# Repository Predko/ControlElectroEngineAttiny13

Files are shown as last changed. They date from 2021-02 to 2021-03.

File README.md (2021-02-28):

# ControlElectroEngineAttiny13

Прошивка для Attiny13.
Предназначена для управления запуском трёхфазного ассинхронного двигателя, подключённого к двухфазной сети.
Запуск осуществляется путём подключения пускового конденсатора с помощью реле.
Микроконтроллер замеряет ток через фазу двигателя с помощью датчика тока(ACS712, 30А) 
и при превышении значения тока в 1.5 раза, подключает пусковой конденсатор.
Если через 3 секунды ток не уменьшается, двигатель отключается на 10 секунд, при этом подаётся звуковой сигнал.
Затем цикл запуска повторяется.
Если за 3 цикла запуска, двигатель не запустился, питание отключается.

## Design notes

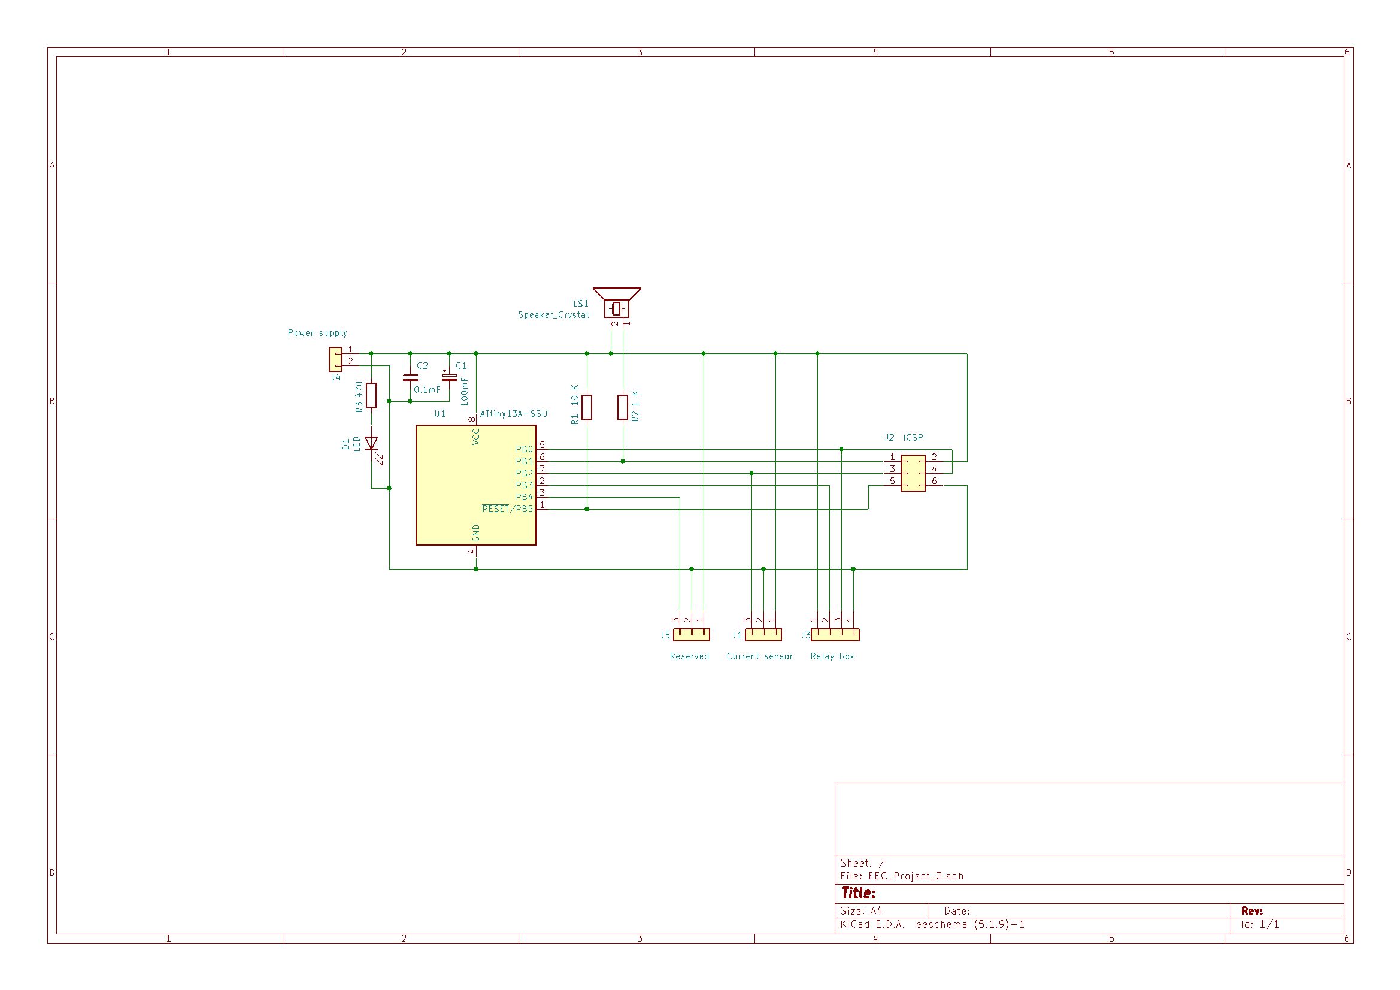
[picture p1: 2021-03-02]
Schema_V2.jpg

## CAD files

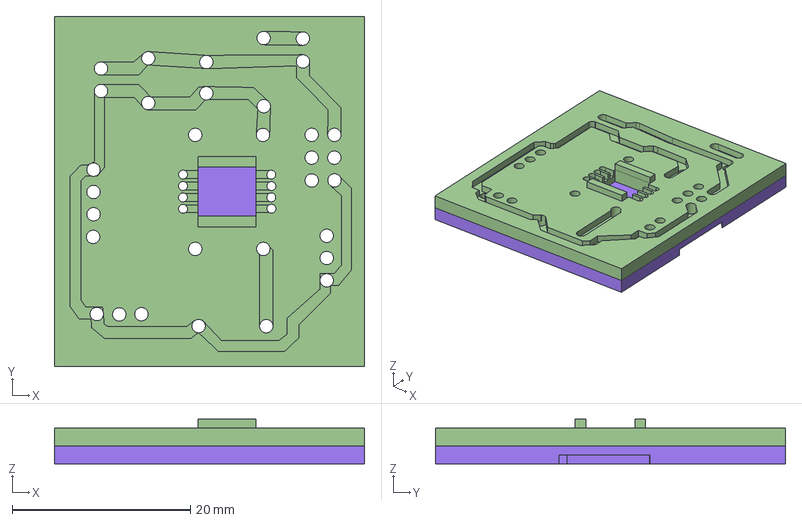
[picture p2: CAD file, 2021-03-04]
PCB/FreeCad/ControlElectroEngine.FCStd
34.7 x 39.2 x 5.00 mm
Slice.0
Slice.1

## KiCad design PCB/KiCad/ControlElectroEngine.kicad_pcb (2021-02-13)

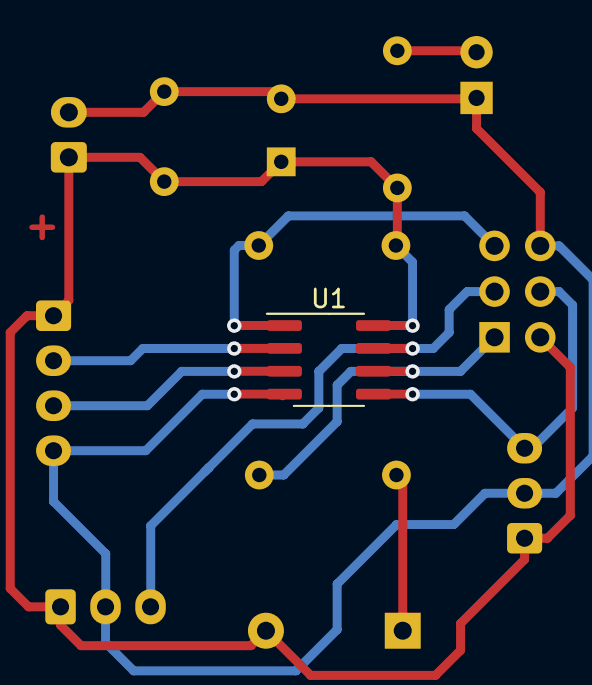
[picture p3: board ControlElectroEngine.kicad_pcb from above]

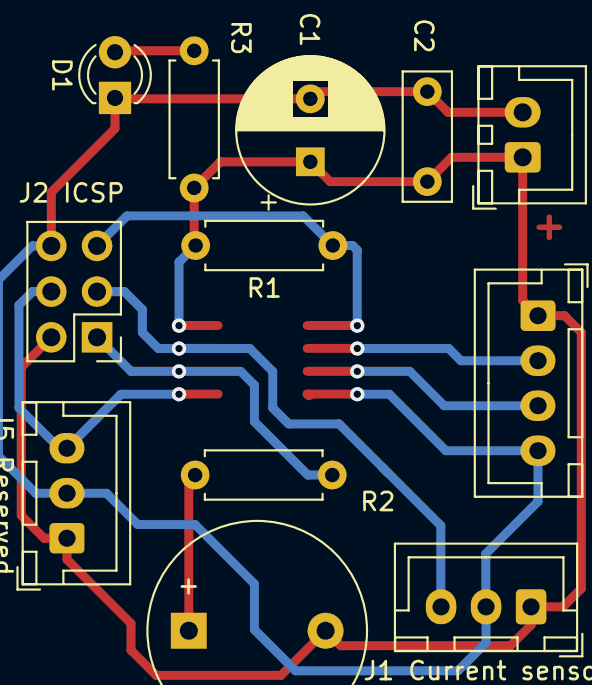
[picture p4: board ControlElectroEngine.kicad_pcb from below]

Board: 2 copper layers, 13 parts (12 on the bottom side), 10 nets.

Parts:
C1: 100mF; CP_Radial_D8.0mm_P3.50mm
C2: 0,1mF; C_Disc_D7.0mm_W2.5mm_P5.00mm
D1: LED; LED_D3.0mm_Clear
J1 Current sensor: Current sensor; JST_XH_B3B-XH-A_1x03_P2.50mm_Vertical
J2 ICSP: ICSP; PinHeader_2x03_P2.54mm_Vertical
J3 Relay: Relay box; JST_XH_B4B-XH-A_1x04_P2.50mm_Vertical
J4 5v: Power supply; JST_XH_B2B-XH-A_1x02_P2.50mm_Vertical
J5 Reserved: Reserved; JST_XH_B3B-XH-A_1x03_P2.50mm_Vertical
LS1: Speaker_Crystal; Buzzer_12x9.5RM7.6
R1: 10 K; R_Axial_DIN0207_L6.3mm_D2.5mm_P7.62mm_Horizontal
R2: 1 K; R_Axial_DIN0207_L6.3mm_D2.5mm_P7.62mm_Horizontal
R3: 470; R_Axial_DIN0207_L6.3mm_D2.5mm_P7.62mm_Horizontal
U1: ATtiny13A-SSU; SOIC-8_3.9x4.9mm_P1.27mm

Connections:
unnamed: C1.1, C2.1, J1 Current sensor.1, J2 ICSP.2, J3 Relay.1, J4 5v.1, J5 Reserved.1, LS1.2, R1.2, R3.2, U1.8
unnamed: C1.2, C2.2, D1.1, J1 Current sensor.2, J2 ICSP.6, J3 Relay.4, J4 5v.2, J5 Reserved.2, U1.4
unnamed: D1.2, R3.1
unnamed: J1 Current sensor.3, J2 ICSP.3, U1.7
unnamed: J2 ICSP.1, R2.2, U1.6
unnamed: J2 ICSP.4, J5 Reserved.3, U1.5
unnamed: J2 ICSP.5, R1.1, U1.1
unnamed: J3 Relay.2, U1.2
unnamed: J3 Relay.3, U1.3
unnamed: LS1.1, R2.1

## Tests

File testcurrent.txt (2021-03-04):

:1
F2		242	
F3		243
3601	310
8A FE F3 F3 F3 F3 F3 F3 F3 F3 F3 B1 B2 00 F2 0D F2 F2 AD 8B 8C 84 8E

17
EB01

:2
F1 F2
1801
F2 F3 F2 F2 F2 F2 F3 F2 F2 F2 F2 F2 F1 F2 F1 F2 F2 F2 F1 F2 F1 - с конденсатором 21 изм
AF AE B1 AF B0 B2 AF B1 B0 AF B1 B0 AF B0 B1 AF B2	- без 17 изм
0000
26 - число измерений
5A02

F3 F3 
1701

F3 F3 F3 F3 F2 F3 - 243 = 24 А
F3 F3 F3 F3 F3 F3 F3 F3 F3 F3 F3 F3 F3 F3

00
14
00 Отключение конденсатора.
					B0 = 176 = 10 А
F2 AE AD B0 B1 25 AE B1 AE B1 B0 AF B1 B1 B0 B1 B1 B0 B0 B1 B1

0000

28

5702

:3
Старт.
F1 F1 	- 241 = 23.65 А
1901 

F1 F1 F1 F1 F1 F0 
Включение конденсатора.
{F1 E6} ED EF F0 E8 EF EF F1 EF F1 EF EA F0 	- (21.35 - 23.65 А)
{время запуска ~ 0.5 сек)
00 14 00
Отключение конденсатора.
F1 B5 B3 B4 B3 68 B4 B4 B3 B5 B5 B5 B4 B5 B3 B5 B4 B5 B5 - B4 = 10.0 А

0000

26

6002

5702

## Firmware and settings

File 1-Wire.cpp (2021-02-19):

    // https://forum.sources.ru/index.php?showtopic=381077
    #include <inttypes.h>
    #include <string.h>
    #include <avr/io.h>
    #include <util/delay.h>
    #include <avr/interrupt.h>
     
    // --- Configuration for OneWire
    #define ONEWIRE_PORTReg     PORTB
    #define ONEWIRE_DDRReg      DDRB
    #define ONEWIRE_PINReg      PINB
    #define ONEWIRE_PIN         PB0
     
    // --- Configure for PWM (fan)
    #define PWM_PORTReg         PORTB
    #define PWM_DDRReg          DDRB
    #define PWM_PIN             PB1
     
    // - Minimal temperature to activate fan
    #define FAN_MIN_TEMPERATURE 40
     
    // - Temperature for maximum fan power
    #define FAN_MAX_TEMPERATURE 70
     
    // - Power, used to start fan. Must be enough to start!
    #define FAN_START_PWM_VALUE 200
    #define FAN_START_TIME      2000
     
    // - Minimal fan power
    #define FAN_MIN_POWER       60
     
    // - Maximal fan power
    #define FAN_MAX_POWER       255
     
    // - Configure for alarm
    #define ALARM_PORTReg               PORTB
    #define ALARM_DDRReg                DDRB
    #define ALARM_PIN                   PB2
     
    #define ALARM_ON_MAX_ERRORS         16
    #define ALARM_ON_MAX_TEMPERATURE    80
     
     
     
    // - Set OneWire pin in Output mode
    #define OneWire_setPinAsOutput  ONEWIRE_DDRReg |= (1<<ONEWIRE_PIN)
     
    // - Set OneWire pin in Input mode
    #define OneWire_setPinAsInput   ONEWIRE_DDRReg &= ~(1<<ONEWIRE_PIN)
     
    // - Set LOW level on OneWire pin
    #define OneWire_writePinLOW     ONEWIRE_PORTReg &=  ~(1<<ONEWIRE_PIN)
     
    // - Set HIGH level on OneWire pin
    #define OneWire_writePinHIGH    ONEWIRE_PORTReg |= (1<<ONEWIRE_PIN)
     
    // - Read level from OneWire pin
    #define OneWire_readPin         ( ( ONEWIRE_PINReg & (1<<ONEWIRE_PIN) ) ? 1 : 0 )
     
     
    // - Turn on alarm
    #define Alarm_On    ALARM_PORTReg |= (1<<ALARM_PIN);
     
    // - Turn off alarm
    #define Alarm_Off   ALARM_PORTReg &= ~(1<<ALARM_PIN);
     
    // - PWM Value ( 0 - off, 255 - max )
    uint8_t PWMValue    = 0;
     
    // - Oveflow counter for PWM
    uint8_t PWMCounter  = 0;
    uint8_t PWM         = 0;
     
     
    //! Calculate CRC-8
    uint8_t crc8(const uint8_t * addr, uint8_t len){
        uint8_t crc = 0;
        while (len--) {
            uint8_t inbyte = *addr++;
            for (uint8_t i = 8; i; i--) {
                uint8_t mix = (crc ^ inbyte) & 0x01;
                crc >>= 1;
                if (mix) crc ^= 0x8C;
                inbyte >>= 1;
            }
        }
        return crc;
    }
     
    //! Reset function
    uint8_t OneWire_reset(){
        
        // - Wait for line
        uint8_t Retries = 125;
        OneWire_setPinAsInput;
        do{
            if( --Retries == 0 ) return 0;
            _delay_us( 2 );
        }while( !OneWire_readPin );
        
        // - Drop line
        OneWire_writePinLOW;
        OneWire_setPinAsOutput;
        _delay_us( 480 );
        
        // - Listen for reply pulse
        OneWire_setPinAsInput;
        _delay_us( 70 );
        
        // - Read line state
        uint8_t State = !OneWire_readPin;
        _delay_us( 410 );
        return State;
    }
     
    //! Write single bit
    void OneWire_writeBit( uint8_t Bit ){
        if( Bit & 1 ){
            // - Drop line
            OneWire_writePinLOW;
            OneWire_setPinAsOutput;
            // - Write Bit-1
            _delay_us( 10 );
            OneWire_writePinHIGH;
            _delay_us( 55 );
        }else{
            // - Drop line
            OneWire_writePinLOW;
            OneWire_setPinAsOutput;
            // - Write Bit-0
            _delay_us( 65 );
            OneWire_writePinHIGH;
            _delay_us( 5 );
        }
    }
     
    //! Read single bit
    uint8_t OneWire_readBit(){
        // - Drop line
        OneWire_setPinAsOutput;
        OneWire_writePinLOW;
        _delay_us( 3 );
        
        // - Wait for data
        OneWire_setPinAsInput;
        _delay_us( 10 );
        
        // - Read bit into byte
        uint8_t Bit = OneWire_readPin;
        _delay_us( 53 );
        return Bit;
    }
     
    //! Write byte
    inline void OneWire_writeByte( const uint8_t Byte, uint8_t Power = 0 ){
        
        // - Write each bit
        for( uint8_t BitMask = 0x01; BitMask; BitMask <<= 1 ) OneWire_writeBit( (BitMask & Byte) ? 1 : 0 );
        
        // - Disable power
        if( !Power ){
            OneWire_setPinAsInput;
            OneWire_writePinLOW;
        }
    }
    //! Read byte
    inline uint8_t OneWire_readByte(){
        uint8_t Byte = 0;
        
        // - Read all bits
        for( uint8_t BitMask = 0x01; BitMask; BitMask <<= 1 ){
            // - Read & store bit into byte
            if( OneWire_readBit() ) Byte |= BitMask;
        }
        return Byte;
    }
     
     
    //! Read buffer
    inline void OneWire_read( uint8_t * Buffer, uint8_t Size ){
        for( uint8_t i = 0; i < Size; i++ ) Buffer[ i ] = OneWire_readByte();
    }
     
    //! Write buffer
    inline void OneWire_write(const uint8_t * Buffer, uint8_t Size, uint8_t Power = 0 ){
        for( uint8_t i = 0; i < Size; i++ )  OneWire_writeByte(  Buffer[ i ] );
        if( !Power ){
            // - Disable power
            OneWire_setPinAsInput;
            OneWire_writePinLOW;
        }
    }
     
    //! Map one range to another
    uint16_t map( uint16_t x, uint16_t in_min, uint16_t in_max, uint16_t out_min, uint16_t out_max){
      return (x - in_min) * (out_max - out_min) / (in_max - in_min) + out_min;
    }
     
     
    //! Main function
    int main() {
        
        // - Configure alarm pin
        ALARM_DDRReg |= ( 1 << PB2 );
        
        // - Configure PWM pin
        PWM_DDRReg |= ( 1 << PB1 );
        
        // - Configure timer for PWM
        TIMSK0      = 0b00000010;
        TCCR0B      = 0b00000001;
        
        // - Allow interrupts
        sei();
        
        // - Buffer for ROM
        uint8_t ROM[ 9 ];
        
        // - Fan state
        uint8_t FanState    = 0;
        
        // - Error count
        uint8_t ErrorCount  = 0;
        
        // - Main loop
        while( 1 ){
            // - Check error count
            if( ErrorCount >= ALARM_ON_MAX_ERRORS ){
                // - Force start fan at 100% power
                PWMValue    = 255;
                FanState    = 1;
                ErrorCount  = 0;
                // - Turn on alarm pin
                Alarm_On;
            }
            
            // - Prepare for new cycle
            _delay_ms( 500 );
            memset( ROM, 0, sizeof( ROM ) );
            
            // - Start conversion
            if( !OneWire_reset() ){
                // - Report error
                ErrorCount++;
                continue;
            }
            OneWire_writeByte( 0xCC, 1 );
            OneWire_writeByte( 0x44, 1 );
            
            // - Wait until conversion finished
            _delay_ms( 1000 );
            
            // - Read ROM
            if( !OneWire_reset() ){
                // - Report error
                ErrorCount++;
                continue;
            }
            OneWire_writeByte( 0xCC, 1 );
            OneWire_writeByte( 0xBE, 1 );
            OneWire_read( ROM, sizeof( ROM ) );
            
            // - Check ROM CRC
            if( crc8( ROM, 8 ) != ROM[ 8 ] ){
                // - Report error
                ErrorCount++;
                continue;
            }
            // ------------------------------------------------------------------
            // - Reset error count & turn alarm off
            ErrorCount = 0;
            Alarm_Off;
            // ------------------------------------------------------------------
            
            // --- Get 8-bit temperature
            // - Construct 16-bit register value from 0 and 1 bytes of ROM.
            // - Remove float part (4 right bits) to get interger value
            uint8_t     Temperature     = ((( ROM[ 1 ] << 8 ) | ROM[ 0 ]) >> 4 );
            
            // - Disable fan when temperature lower than 40* celsius
            if( Temperature < FAN_MIN_TEMPERATURE ){
                // - Stop fan
                PWMValue = 0;
                FanState = 0;
                continue;
            }
            
            // - Start fan if stopped
            if( !FanState ){
                PWMValue = FAN_START_PWM_VALUE;
                _delay_ms( FAN_START_TIME );
                FanState = 1;
            }
            
     
            // - Alarm if overheated
            if( Temperature > ALARM_ON_MAX_TEMPERATURE ){
                
                // - Turn alarm on
                Alarm_On;
                _delay_ms( 100 );
                
                // - Turn alarm off
                Alarm_Off;
            }
     
            // - Set fan power
            uint16_t Power = map( Temperature,
                FAN_MIN_TEMPERATURE,    FAN_MAX_TEMPERATURE,
                FAN_MIN_POWER,          FAN_MAX_POWER
            );
            
            // - Limit power to max PWM
            if( Power > 255 ) Power = 255;
            
            // - Set fan power
            PWMValue = Power;
            
        }
     
    }
     
    //! PWM
    ISR( TIM0_OVF_vect ){
        
        // - Set PWM pin HIGH on each PWM counter overflow
        if( ++PWMCounter == 0 ){
            PWM = PWMValue;
            PWM_PORTReg |= (1<<PWM_PIN);
        }
        
        // - Set PWM pin LOW when PWM counter == PWMValue
        if( PWMCounter == PWM ) PWM_PORTReg &= ~(1<<PWM_PIN);
    }

    uint8_t one_wire::exchange(uint8_t data)
    {
        PORTC &= ~BIT_MASK;
        uint8_t Counter = 8;
        do
        {
            bool Result = exchange_bit(data & (1<<0));
            data  = Result ? (data >> 1) | (1 << 7) : data >> 1;
        }
        while (--Counter);
        PORTC |= BIT_MASK;
        return data;
    }
     
    inline bool one_wire::exchange_bit(bool data)
    {
        DDRC |= BIT_MASK;
        _delay_us(7);
        if(data)
            DDRC &= ~BIT_MASK;
        _delay_us(8);
        data = PINC & BIT_MASK;
        _delay_us(45);
        DDRC &= ~BIT_MASK;
        _delay_us(1);
        return data;
    }

/*
    PWMValue = Temperature; // * 2; // - 40;
 
    buffer2[0]=PWMValue % 10;
    PWMValue/=10;
    buffer2[1]=PWMValue % 10;
    PWMValue/=10;
    buffer2[2]=PWMValue % 10;
    PWMValue/=10;
    buffer2[3]=PWMValue % 10;
        nlcd_GotoXY(4,4);
        nlcd_Putc(0x30+buffer2[3]);
        nlcd_GotoXY(5,4);
        nlcd_Putc(0x30+buffer2[2]);
        nlcd_GotoXY(6,4);
        nlcd_Putc(0x30+buffer2[1]);
        nlcd_GotoXY(7,4);
        nlcd_Putc(0x30+buffer2[0]);
*/

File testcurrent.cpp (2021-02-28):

//
// NO WARRANTEE OR GUARANTEES!
// Written by Victor Predko 
// You are free to use, redistribute and modify
// 
// 
// 1.2 MHz, built in resonator
// 
//
// Created: 25.12.2020 13:17:20
//  Author: Predko Victor
// 
// ATMEL ATTINY13
//	Вариант 1.
//                            
//                                              	 +-\/-+
//	   					(PCINT5/RESET/ADC0/dW) PB5  1|    |8  Vcc
//	Power supply relay -    (PCINT3/CLKI/ADC3) PB3  2|    |7  PB2 (SCK/ADC1/T0/PCINT2) 				- Current sensor pin
//	Start relay	       -    	 (PCINT4/ADC2) PB4  3|    |6  PB1 PWM (MISO/AIN1/OC0B/INT0/PCINT1) 	- Tone port
//                                  		   GND  4|    |5  PB0 PWM (MOSI/AIN0/OC0A/PCINT0)		- Reserved
//                                             		 +----+
//	Вариант 2.
//                            
//                                              	 +-\/-+
//	   					(PCINT5/RESET/ADC0/dW) PB5  1|    |8  Vcc
//	Power supply relay -    (PCINT3/CLKI/ADC3) PB3  2|    |7  PB2 (SCK/ADC1/T0/PCINT2) 				- Current sensor pin
//	Reserved	       -    	 (PCINT4/ADC2) PB4  3|    |6  PB1 PWM (MISO/AIN1/OC0B/INT0/PCINT1) 	- Tone port
//                                  		   GND  4|    |5  PB0 PWM (MOSI/AIN0/OC0A/PCINT0)		- Start relay
//                                             		 +----+

// Программа проверки работы системы считывания датчика тока.
// Так же сохраняет в EEPROM значения тока, потребляемого двигателем в момент запуска.

#include "main.h"
#include <avr/io.h>
#include <util/delay.h>
#include <avr/eeprom.h>

#include "AnalogIO_1_2Mhz.h"
#include "wddelay.h"
#include "soundsignals.h"
#include "tone.h"



// Время измерения в 32 мсекундных интервалах (примерно три полных цикла тока сети 50Гц)
const uint16_t  measurementTime = 64 / 32;

// 66 mV / 1 A   - 30 A sensor
// 100 mV / 1 A  - 20 A sensor
// 185 mV / 1 A  - 5 A sensor

// 30A sensor
#define K_Current 66L

#define operatingCurrent 10  // (Ampere)

#define KStartCurrent 2.0	// Коэффициент превышения тока для начала процедуры запуска.

// (K_Current * 256 * 1.414 * KStartCurrent) / 5000.0)
#define K0 (float)((K_Current * 256 * 1.414 * KStartCurrent) / 5000.0)	// для 66l = 7.167

const uint8_t *startSensorValueEepromPtr = (uint8_t *)0;
// Значение сенсора тока, выше которого начинается процедура запуска двигателя.
#define startSensorValue (uint8_t)(128.0 + (operatingCurrent * K0))	// 228

const uint16_t *maxStartTimeEepromPtr = (uint16_t *)1;

// Максимальное время старта (миллисекунд))
uint16_t maxStartTime = 4800 / 32;

const uint8_t *MaximumStartAttemptsEepromPtr = (uint8_t *)3;

// Максимальное количество неудачных попыток запуска.
uint8_t MaximumStartAttempts = 3;

#define SIZE_ARRAY_CURRENTS 30

uint8_t CurrentValues[SIZE_ARRAY_CURRENTS];

void TestCurrent()
{
   	ReadySound();

	_delay_ms(8000);

	ReadySound();

	PowerOn();

	_delay_ms(200);
	uint8_t oldCurrentValue = getMaxCurrentSensorValue();

	uint8_t *eepAdr = (uint8_t *)0;

	eeprom_write_byte(eepAdr++, oldCurrentValue);

	_delay_ms(200);
	
	oldCurrentValue = getMaxCurrentSensorValue();

	eeprom_write_byte(eepAdr++, oldCurrentValue);

	uint16_t startTime = Wdt_GetCurrentMsCount();
	
	eeprom_write_word((uint16_t *)eepAdr, startTime);
	eepAdr += 2;

	uint8_t i = 0;

	while (!Wdt_IsTimerEnded(startTime, 5120 / 32))
	{
		eeprom_write_byte(eepAdr++, getMaxCurrentSensorValue());

		_delay_ms(300);
		i++;

		if (i == 5)
		{
			CapacitorOn();

			
		}
	}
	
	CapacitorOff();

	eeprom_write_byte(eepAdr++, 0);
	eeprom_write_byte(eepAdr++, i);
	eeprom_write_byte(eepAdr++, 0);

	while (!Wdt_IsTimerEnded(startTime, 10240 / 32))
	{
		eeprom_write_byte(eepAdr++, getMaxCurrentSensorValue());

		_delay_ms(300);
		i++;
	}
	
	PowerOff();

	eeprom_write_word((uint16_t *)eepAdr, 0);
	eepAdr += 2;

	eeprom_write_byte(eepAdr++, i);
	eeprom_write_word((uint16_t *)eepAdr, Wdt_GetCurrentMsCount());

	AlarmSound(2);

	while(1)
	{
	}
}


int main(void)
{
	Setup();

	TestCurrent();
}

void Setup()
{
	OutputPinsInit();

	Adc_Setup();
	
	Wdt_Timer_Enable();
}

uint8_t getMaxCurrentSensorValue()
{
uint8_t sensorValue;             // value read from the sensor
uint8_t sensorMax = 0;

	uint16_t startTime = Wdt_GetCurrentMsCount();

	do
	{
		sensorValue = Adc_Read();
		
		if (sensorValue > sensorMax)
		{
			sensorMax = sensorValue;
		}
	}
	while(!Wdt_IsTimerEnded(startTime, measurementTime));

	return sensorMax;
}

void OutputPinsInit()
{
	// Output mode
	DDRB |= START_RELAY;
	DDRB |= SUPPLY_RELAY;
}

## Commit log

2020-12-29 Программа управления микроконтроллером Attiny13. Предназначена для запуска ассинхронного трёхфазного двигателя, от однофазной сети, путём подключения пускового конденсатора. Программа измеряет ток , 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
2020-12-29 Реализация программной задержки сделана с использованием прерывания watchdog. Не протестировано.
2021-01-02 Изменён таймер WatchDog.
2021-01-03 Отлажена работа временной задержки с использованием прерывания watchdog.
2021-01-03 Отлажена работа генерации звуковых сигналов
2021-01-10 Отлажено считывание данных сенсора тока. Отлажена работа задержки с использованием таймера WatchDog. Программа протестирована. Требуется настройка параметров запуска - пусковой ток, рабочий ток.
2021-01-11 Отлажена программа сбора информации о значениях токов во время старта и работы двигателя.
2021-02-13 Уменьшена разрядность измерения АЦП до 8 бит, с соответствующим изменением связанных функций.
    [B_CU.stl, B_F_CU.3mf, EEC_Project-F_Cu.dxf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]
2021-02-13 Изменён Makefile - компилляция и сборка перенесена в каталог build.
    [Schema.sch]
2021-02-19 Тестирование датчика тока. Проблема - не удаётся получить запись правильных значений в EEPROM
2021-02-20 Изменена структура файлов проекта: - удалена папка тестового проекта, - тестовый файл перенесён в основную папку, - запуск make файла с указанием имени цели, позволяет собирать основной файл или файл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
2021-02-25 Отлажена работа тестирования пуска
2021-02-26 Изменён пин стартового реле на PB0
2021-02-27 Изменены пины
2021-02-27 Исправлена ошибка аналогово чтения
    [EEC_Project_1-1.kicad_pcb, EEC_Project_2.kicad_pcb, EEC_Project_2.sch]
2021-02-28 Переименован каталог схем и печатных плат
    [B_CU.stl, B_F_CU.3mf, ControlElectroEngine.sch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]
2021-02-28 Добавлены файлы Readme и LICENSE
2021-02-28 Отработана процедура старта.
2021-03-02 Изменена структура и названия папок проекта.
    [B_CU.stl, B_F_CU.3mf, ControlElectroEngine.FCStd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]
2021-03-04 Изменён алгоритм запуска двигателя. Добавлено описание алгоритма запуска двигателя.
    [ControlElectroEngine.FCStd]
